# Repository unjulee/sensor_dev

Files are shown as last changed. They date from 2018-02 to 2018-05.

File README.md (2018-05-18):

# sensor_dev
The sensor development team's repo.

## Website
* Please visit our site at [aguaclara.github.io/sensor_dev/](https://aguaclara.github.io/sensor_dev/)

## Team members
* Lois Lee (LL556)
* Srilekha Vangavolu (SV397)
* Hannah Si (HS649)

## Semester Goals
* Our goal is to create a lowcost but efficient concentration detector by essentially hijacking cheap endoscopes/borescopes and merging its function with code and physical additions of our own. By designing a mobile application that utilizes image processing and basic equations relating the image values to concentrations, we can both get a visual of what is going on in each level of depth and determine using a threshold value where the sludge blanket begins.

## Links to Reports and Presentations

[Midterm Symposium Spring 2018](https://docs.google.com/presentation/d/1DQyx87q7LtW5yOaPytrrnAvyGNLM-DLOTYY6XjQVZQw/edit?usp=sharing)
[Final Symposium Spring 2018](https://docs.google.com/presentation/d/1z8MEi4Bpe6GwdDxDbs89RpllG_0ilBI8o5UYnoSLq9U/edit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)

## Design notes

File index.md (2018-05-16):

# Submersible Sensor

Throughout the semester, we will update this page with current tasks, projects completed,
and other things we want to have easy access to.

## About Us

Our goal is to create a lowcost but efficient concentration detector by essentially hijacking 
cheap endoscopes/borescopes and merging its function with code and physical additions of our own.
By designing a mobile application that utilizes image processing and basic equations relating 
the image values to concentrations, we can both get a visual of what is going on in each level of depth
and determine using a threshold value where the sludge blanket begins.

The current members of this subteam are 

* Lois Lee (LL556) 
* Srilekha Vangavolu (SV397)
* Hannah Si (HS649)

## Srilekha's CAD rendering of the MAPE design.
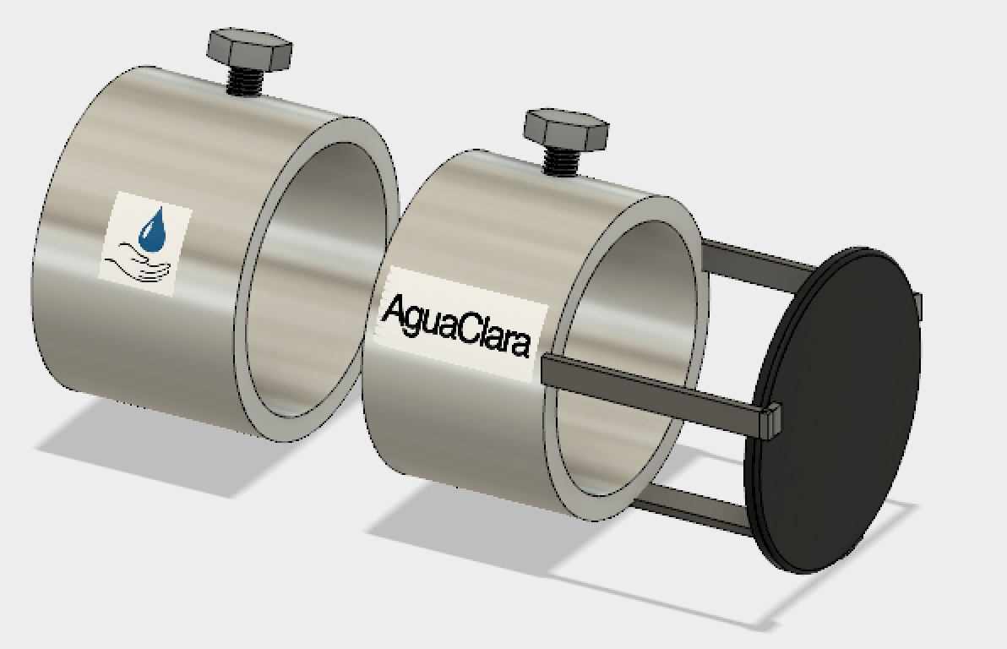
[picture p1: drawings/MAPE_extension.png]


Here is the ruler system we are currently fabricating:

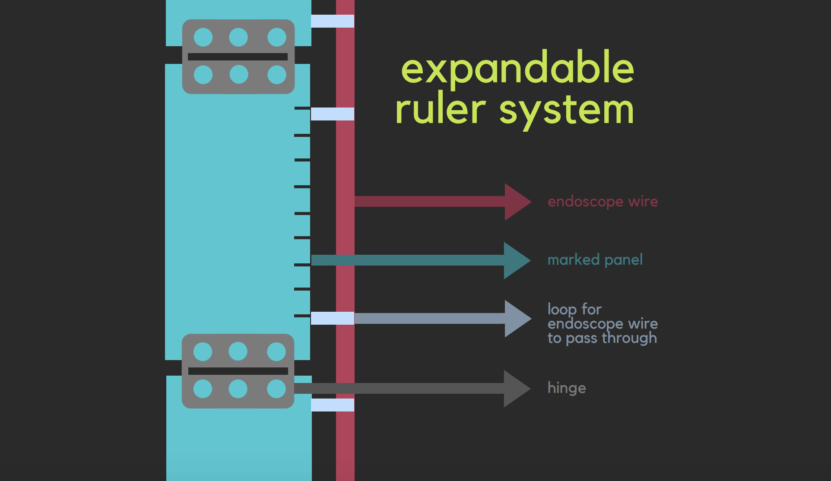
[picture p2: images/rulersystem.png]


To learn more about the specifics of our subteam, please look through the tabs below.

* [Logbook](./logs/logs.md)
* [Manuals](./manuals/manuals.md)
* [Drawings](./drawings/drawings.md)
* [Code](./code/code.md)

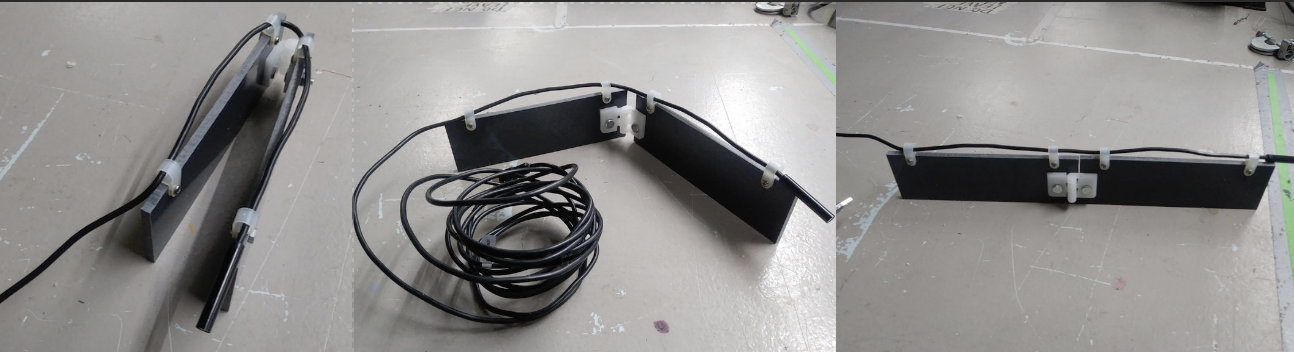
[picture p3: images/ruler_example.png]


## Current Tasks

  - Currently working on fabrication of an expandable ruler system for MAPE design.
  - Currently working on endoscope attachment fabrication and supplies.

Learn more about each of the [components](./components/components.md) of our sensor plan.

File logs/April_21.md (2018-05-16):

It's been a while since we've logged what we've been doing, mostly because we've been looking into supplies.

**Week of April 21st**

Fabrication of the expandable ruler system:
The expandable ruler system replaces our original idea for the reel, just because the reel would not be able to straighten out the
semi-rigid cable for the endoscope. We are using panels connected by hinges with loops on the side to hold the endoscope cable.
The panels will be marked like a ruler so that we can read the height. Some comments on the system:
  - Single hinges didn't work for us, so we may have to use double hinges.
  - In future prototypes, may be thinner.
  
Fabrication of the endoscope attachment:
  - We've found a temporary solution to our matte surface, and also, Hannah's computer case also absorbs almost all light, and we
  realise that color won't be much of a concern for us since it will be greyscaled anyways.
  - We've bought thick wires for the prongs, and also looked for some matte paint, but it is no longer necessary and anyways the most
  matte paint was not good enough.
  - We still need some cylinder shaft collar that will wrap around, and also we need to weld the metal together. 
  
Regarding the light gain problem, we've decided to just black out one half of the endoscope camera and use that as a control since we
can't access the light gain code from the developers of the endoscope. We're still looking for the best way to do that since black tape seems 
not to work as well as we'd like.

51mm for each spacer without screw part

48mm+15 for distance from plate and  endoscope 63

63-51=12 mm

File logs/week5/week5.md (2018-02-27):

# Week 5

We've started preliminary testing using the turbidity sensor after some minor issues regarding connectivity.
We realized that the relation they gave us only works for the voltage range of 2.5-4.2 so we need to set boundaries to make sure we have
a value that makes sense, or output a print statement that accurately shows the lack of information anywhere outside the range.

We've also got our hands on an arduino add on board which could allow us to use bluetooth instead of a cable if we buy an addon.
We got ourselves two pushbuttons from this board but we may need more?

Also we may not need the pushbutton yet, we can just use the reset button and have it determine the offset when we reset manually.

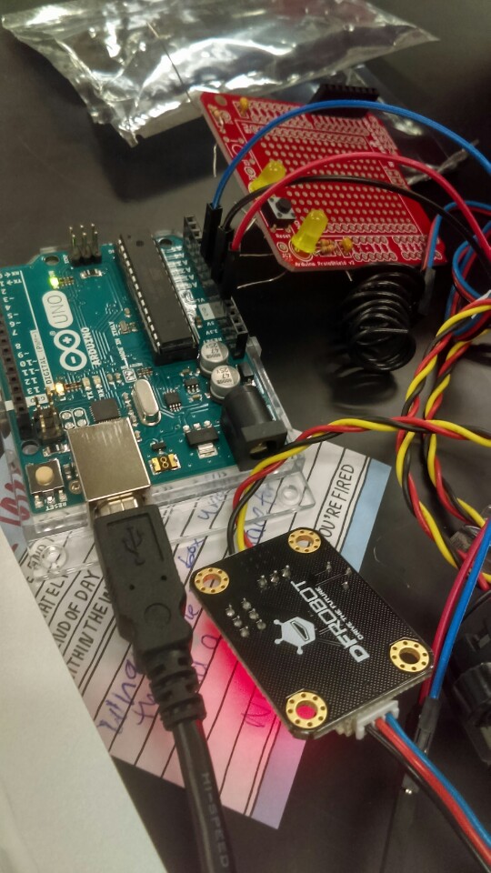
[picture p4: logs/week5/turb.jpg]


THINGS TO DO/ASK:

Is the floc hopper tube smooth?
Also since it's slanted how exactly we are measuring sludge blanket height.
Ask about dark colored sediments

Tasks for next time:
Waterproofing turbidity sensor
Making testing tube (kind of deep)
Once we finish tube start experimenting with borescope.

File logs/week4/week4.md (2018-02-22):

  - Work on testing the turbidity sensor using arduino and code
  - Adjust the relation as necessary
  - Play around with endoscope, maybe start to write pseudocode.
  - Make larger container with matte dark walls and bottom.

  We got access to the maker lab after the training. They have an arduino thankfully so we'll use that for the turbidity sensor.
  We also did some preliminary testing using the endoscope. Mostly trying it out in vials and seeing how it works. The problem is that the 
  LED gives off a reflection so we need a bigger matte wall tank that won't light up.

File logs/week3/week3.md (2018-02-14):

This week we are working on the LED, training and possibly playing around with the turbidity sensors.

* Tuesday
Instead of making the LED, we are looking into buying a small flashlight that is waterproof/water resistant.
Also with the size of the flocc hopper, we need to rethink our entire plan.

```arduino
/*
 * THIS CODE IS FOR AGUACLARA SENSOR_DEV
 * This code's function is to take the input voltage from the turbidity sensor
 * and translate it into a numerical value representing turbidity
 */

int ledPin = 13;

void setup() {
  Serial.begin(9600); //Baud rate: 9600 (this is used for serialPrint)
  pinMode(ledPin, OUTPUT);  //This is to set up the LED
}

void loop() {
  int sensorValue = analogRead(A0);// read the input on analog pin 0:
  float voltage = sensorValue * (5.0 / 1024.0); // Convert the analog reading (which goes from 0 - 1023) to a voltage (0 - 5V):
  Serial.println("this is the voltage reading:");
  Serial.print(voltage); // print out the value you read:
  delay(500);
  Serial.println("converted turbidity:");

  //threshold value to compare to light up LED
}
```

**Displays**
  * We are talking about different displays to display the numerical value. 
  Hannah found a great display that's very affordable.

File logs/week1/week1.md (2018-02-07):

# Week 1
Aguaclara notebook:

* **Get endoscope/borescope (sometimes called snake camera)**
    - buy cheap but okay quality
    - doesn’t have to be good quality because we only need rough idea 
    - But okay because may be used for other things
    - Must be long enough (at least 2m ≈ 6.5ft)
* **Make the cage:**
    - Face camera laterally rather than vertically
    - The cage should also fit an LED screen on opposite side
    - Do you mean: Have LED (single bulb or ring) on opposite side
    - LED should be very bright and close enough so outside light doesn’t interfere
    - Use CAD and 3D printing
    - May need to end a weight on the end so that it’ll sink properly (if device is lowered by a semi-rigid cable, e.g. the endoscope cord)
    - Maybe make it two parts so it clips into place over 
the endoscope and LED
    - To make cage more flexible to multiple lengths/sizes of endoscopes, fix the supporting (hanging) cable relative to the front end of the endoscope 
    - Best if LED is protected with waterproof cage that also holds a removable battery (waterproof phone case?)

* **HEIGHT:**
    - We can have a reel system with notches for a specific length of cord and in that way determine the height of the sludge blanket.

* **LED:**
    - Rubber outing
    - LED connected to battery with a switch/button
    - Keyboard idea: have rubber cover with button over actual button
    - battery

* **Program app:**
    - Connecting the cameras.
    - Confluence camera tab
    - Image Processing
    - OpenCV
    - First connect the endoscope camera to the app
    - Take multiple photos at each level
    - Translate images to grayscale and find average darkness per pixel
    - Average the 3 values and make a relation between the grayscale values and concentration.

* **UI**
    - Kivy
    - Image from endoscope 
    - Need to connect app to usb connected endoscope
    - Take photo button
    - Convert button
    - Using the relation, obviously we need to develop one first through testing and etc.
    - Show the concentration
    - Maybe we could make a conversion button to convert from g/mL and other types of units.

Some notes:
go to the app dev ppl for tips?
ask POST/AIDE what program they use for apps
we should make it an app so it can be used without wifi
The cage maybe can be triangular?
Still have the problem of height?
Upside down ruler system?
SONAR for automatically measuring depth?
Alternative: making ruler markings on the pole that supports the sensors and prompting user to lower it to a specific depth
Secondary consideration: reeling system

Other notes:

Sludge blanket threshold coded in? So after conc conversion, if reaches threshold, tells you you are in the sludge blanket? Maybe then trigger sonar and find distance?

Ask concentration at sludge blanket

How to waterproof circuits?
LED plate...maybe not rechargeable?

https://www.amazon.com/AGPtek-Submersible-Brightness-Battery-Decoration/dp/B00T9GGWGC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 
Something like this but problem with this is that it dims plus cannot turn on and off easily

Even better buy screwable waterproof disc shaped cases, make own led
Waterproof phone case

* [Waterproof case](https://www.amazon.com/Universal-Waterproof-Case-JOTO-CellPhone/dp/B00LBK7QBY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 )
* [LED from Sparkfun](https://www.sparkfun.com/products/13902 )
* [LED from Sparkfun](https://www.sparkfun.com/products/11118)
* [LED from Sparkfun](https://www.sparkfun.com/products/11148)
* [LED from Sparkfun](https://www.sparkfun.com/products/13105)

Endoscope/Borescopes
* [Depstech Endoscope](https://www.amazon.com/Depstech-Semi-rigid-Inspection-Waterproof-Adjustable/dp/B0749BQG1B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)
    - **Pros**: micro USB, USB, USB-C
    - **Cons**: can only dimmed? (possibly solved by covering up?)
    - Resolution: 2.0 MP (1280 x 960)
    - 0.33inch/8.5mm diameter
    - Semi-rigid (bendable, can hold its shape)
* [Endoscope other](https://www.amazon.com/Endoscope-Borescope-Waterproof-Inspection-Adjustable/dp/B01N19YCC3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) 
    - 50 ft, not rigid
    - **Pros:** 
    - **Cons:** “Due to the long cable length, the using experience with android phone is not very good, it will have image delay.”
    - Resolution:1280x720
    - 0.33inch(8.5mm)

PLAN:

Decide on a product
Ask monroe about the Amazon buy
Talk about app with ppl
Work on design for LED
Once the product comes, make a cage

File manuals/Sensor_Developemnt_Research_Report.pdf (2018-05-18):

# Sensor Development, Spring 2018

### Lois Lee, Srilekha Vangavolu, Hannah Si

### May 18, 2018

# Abstract

The goal of the Sensor Development subteam is to create sensors that monitor water quality during the water treatment process. The subteam has previously developed particle concentration and turbidity sensors, including a fluidized bed solids detector for in-lab experiments conducted in piping. This semester, the subteam is designing a submersible solids detector for measuring turbidity and sludge blanket height in sedimentation tanks. The aim is to create a turbidimeter and sludge blanket height detector that is more affordable, easier to fabricate, and more usable than those currently used in the field. Two designs involving an endoscope and photodiode, respectively, are being compared for accuracy and usability.

# Introduction

The Sensor Development subteam creates sensors to monitor water quality in various stages of the AguaClara wastewater and drinking water treatment processes, for purposes not limited to facilitating research, gauging the efficacy of the treatment process, and detecting problems in the treatment process. The subteam's first project was to develop a gas measurement sensor that would improve experimentation in the Anaerobic Fluidized Bed (AFB) Reactor and Upflow Anaerobic Sludge Blanket (UASB) wastewater subteams (Fall 2016 report). (https://www.overleaf.com/read/jyzxckcyzrfz#/20452187/) Afterward, the subteam worked on a fluidized bed solids concentration sensor to measure clay particle concentration in the high rate sedimentation (HRS) process for drinking water treatment. Last semester's team refined the fluidized bed solids concentration sensor, finishing with a working and reliable sensor (Fall 2017 report). (https://www.overleaf.com/10952600qfscwzjvygcj#/41225444/) This semester, the subteam is building a submersible solids concentration sensor to measure turbidity and the height of the sludge blanket in the sedimentation tanks of drinking water treatment plants.

This semester, the Sensor Development subteam is implementing two new designs for a submersible solids concentration, or turbidity sensor based on the two ideas recommended by our advisor and by other AguaClara members. The primary design features an endoscope and visual processing in a mobile application, providing an intuitive and appealing user interface. In the second design, a pre-developed analog turbidity sensor is interfaced with a microcontroller, a system that is easier and cheaper to implement but provides a difficult user interface. The end goal of both designs is to provide the treatment plant operators and members of other subteams with a more affordable, easily used and maintained, and instantaneous method of not only determining the height of the sludge blanket, but also measuring the turbidity of the sedimentation tank fluid at varying depths.

# Manual

# Product Details

Mobile Application-Processed Endoscope (MAPE) Turbidity Sensor

The mobile application-processed endoscope turbidity sensor encompasses three main physical components: 1) the endoscope, 2) an expandable ruler system, and 3) a mobile device, such as a smartphone, provided by the user. The sensor system also contains one software component: a mobile application (on the mobile device), that processes and displays data from the endoscope and interacts with the user.

1. Endoscope

An endoscope is a type of borescope, an optical instrument that is typically slender, illuminated by built in lights, and attached to a long cable, making it suitable for viewing inside otherwise inaccessible places. An endoscope specifically was chosen for this turbidity sensor for its small size, accuracy, water resistance, and device compatibility.

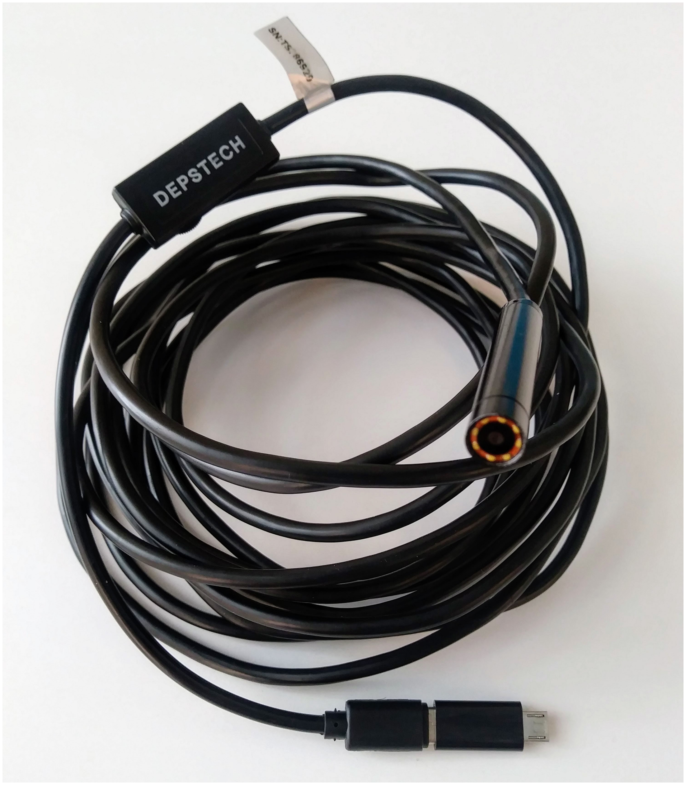
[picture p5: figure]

Figure 1. This endoscope purchased from Depstech® features a 5 meter-long semirigid cable, a 2.0 MP camera ringed with adjustable LED lights, and a type-c USB end with complementary USB and micro-USB extensions. See Special Components for more details.
The role of the endoscope is to capture images of the sedimentation tank fluid at certain depths. The images will be lit by its light source, a ring of LED lights around the camera lens. To restrict its view to such depths, the endoscope is accompanied by a non-reflective material, such as matte rubber, fixed no more than an inch in front of its lens. The turbidity of the fluid is thus measured by intensity of light reflected back to the endoscope due to the presence of suspended solids. In fluid of low solids concentration, the endoscope should detect minimal reflection of light.
2. Expandable Ruler System
Instead of using a marked reel, we are fabricating an expandable ruler system to measuring the length the endoscope has been lowered by. This system consists of multiple 20 cm long PVC panels marked at each centimeter. The panels are connected by hinges to expand and collapse in an accordion style, while the endoscope cable runs down the side of the panels through a series of loops, folding with the panels (see Figure 2). The width of the panels must be around 2 inches or less in order to fit through the sedimentation tank opening.
Thus, the user may lower the system panel by panel until the endoscope has reached the sludge blanket. The height of the sludge blanket would equal the depth of the endoscope (measured by the panel markings) subtracted from the total height of the sedimentation tank. The advantages of this expandable system are its collapsibility, making it ideal for transport, and the rigid backing it provides so that the endoscope wire, which is semi-rigid, remains perpendicular to the bottom of the tank, ensuring an accurate height reading.

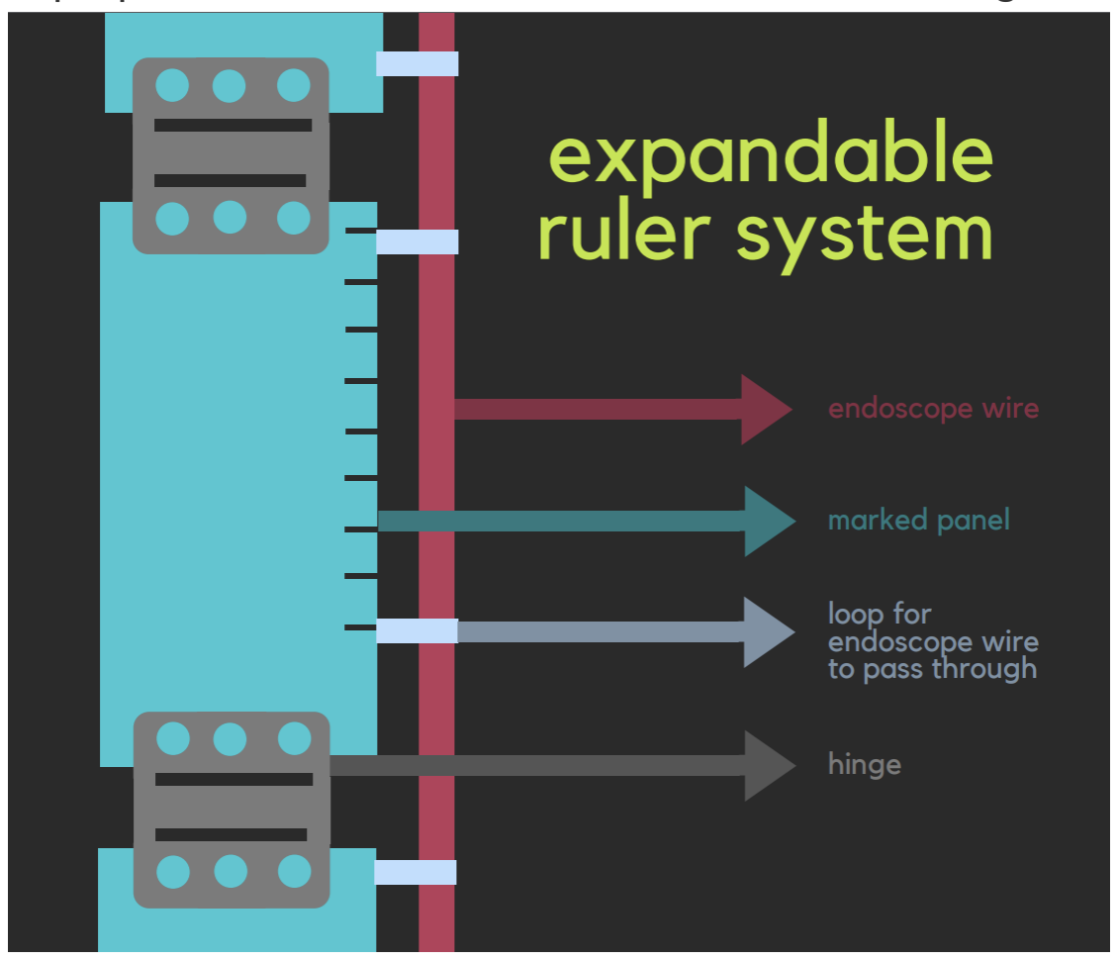
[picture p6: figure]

Figure 2. The expandable ruler system consists of multiple marked panels connected by hinges end-to-end. (Only a portion of the entire system is shown.) The endoscope cable runs down the side of the panels through a series of loops.

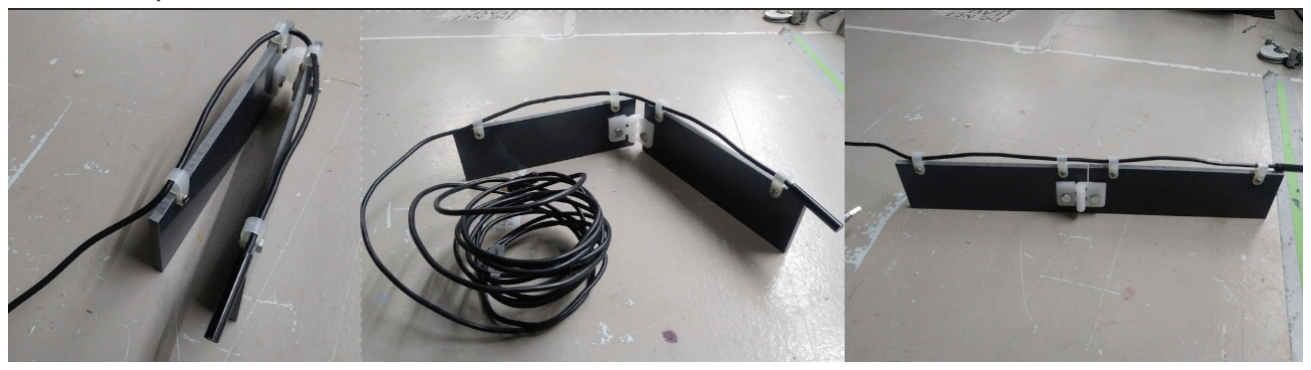
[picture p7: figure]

Figure 3. Above is a prototype of the expandable ruler system, constructed with two PVC panels, plastic loops, and plastic hinges. The prototype is able to collapse (left) for compact storage and also expand (right) to provide a straight, rigid backing for the endoscope cord when hung vertically.
3. Mobile Device and Application

The mobile device is a smartphone or tablet computer provided by the user. It connects to the endoscope by a USB-C, USB, or Micro USB connection and runs the mobile application that we are in the process of programming.
The application will collect live images taken by the endoscope, process each one for average light intensity, and calculate the turbidity of the fluid in each image. This calculation will use an empirically obtained correlation between turbidity and the intensity of reflected light (yet to be developed), as well as offset for any light detected during calibration in clear fluid. See MAPE Code for sample processing code.
The mobile application will also provide a user-friendly interface by directing the user to calibrate the sensor, prompting the user to lower the endoscope to greater depths, and displaying the camera stream and calculated turbidity at each depth. In addition, it will record and graphically plot each calculation to track the change in turbidity as the endoscope nears the sludge blanket. The height of the sludge blanket can be determined once the turbidity rapidly increases or reaches a threshold value.

Microcontroller-Interfaced Analog (MIA) Sensor

The microcontroller-interfaced analog sensor also encompasses three main physical components: 1) the analog photodiode, 2) an expandable ruler system, and 3) a microcontroller programmed to convert and displays data from the endoscope and interact with the user.

1. Analog Photodiode

We had previously been using an analog turbidity sensor, however because of its unreliability and sensitivity to noise, we were forced to use a photodiode instead. The specific photosensor that we used was the TEMT6000 Ambient Light Sensor. See Special Components for details and image source.
2. Expandable Ruler System

This expandable ruler system is the same as that of the MAPES sensor system. We will fabricate it in the same way but the endoscope will be replaced by the photosensor.
3. Microcontroller

The microcontroller we are using is the Arduino® UNO. The Arduino will read the output from the analog photosensor and convert that value into a turbidity reading. The developers of the sensor have published a tentative relation; however, further testing must be done to prove the validity of the relation. If the readings do not correlate to accurate turbidity, we may have to empirically develop a relation of our own. The microcontroller will also feature a digital display for the turbidity reading and a pushbutton for calibrating the sensor in clear fluid.
See Special Components for details on the Arduino microcontroller and MIA Code for sample code.

# Fabrication

Fabrication for the MAPE Turbidity Sensor

The only modification necessary for the endoscope is the addition of an extension for the non-reflective material. The extension includes two rectangular plates, one attached to the endoscope body, and the other extending off the endoscope and holding the non-reflective material in front of the camera lens. The two plates are screwed to and connected by two standoffs. The former standoff contains a hole the size of the endoscope so that the endoscope may slide through and be fixed to the plate with glue or another sealant.

The optimal distance from the camera lens to the non-reflective material is determined as the lowest distance for which the material reflects an acceptably low amount of light (with "acceptable" defined as reflecting light almost uniformly rather than in a bright spot or halo). Note that minimizing the distance minimizes the size and diameter of the sensor. For our endoscope and with matte rubber as the non-reflective material, we estimate a distance of 1.5 cm. Using the distance ( ) and the field of view ( ) angle of the endoscope (60º for ours), the minimum width ( ) of the non-reflective material and the plates is:

All parts can be made of plastic or metal, except the non-reflective material, for which we suggest matte rubber. Below is a rendering of the extension.

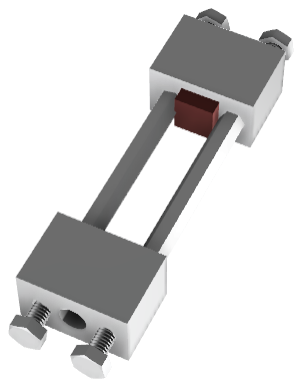
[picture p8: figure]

Figure 5. The extension includes two rectangular plates, one attached to the endoscope body, and the other extending off the endoscope and holding the non-reflective material in front of the camera lens. The two plates are screwed to and connected by two standoffs. Find the Fusion 360™ file for the extension here. (https://github.com/AguaClara/sensor_dev/blob/master/drawings/Endo%20v9.iges)
Variables

Table 1: List of Variables Used in MAPE Sensor Fusion Drawing

Variables | Description | Value
rec_width | width of plate | 2 cm
rec_length | length of plate | 3.5 cm
standoff_diam | diameter of standoffs | .7 cm
rec_thickness | thickness of metal plates | 3 cm
endoscope_diam | diameter of endoscope | 5/16 in
screw_diam | diameter of threads | 5/32 in
disttoedge | distance from screw to edge of plate | .05 cm

D θ
W

W = D ⋅ 2tan(
2

### θ ) = 1.5 ⋅ ≈ 1.732cm 3

2

Variables | Description | Value
screw_leng | length of threads | .6 cm
screw_poly | diameter of hex screw head rubber | .7 cm
chamfer | length of chamfer at bottom of screw | .6 cm
fillet | length of fillet beneath head of screw | .6 cm

Fabrication for the MIA Turbidity Sensor

The main fabrication required for the MIA turbidity sensor is waterproofing the circuitry. The wires are hidden in flexible tubing which is thick enough to make sure that no water will enter and damage the sensor. We are still experimenting with ways to waterproof the photosensor however, because we do not want to damage the circuitry. The LED should be easily waterproofed with some silicon, which we plan to do the following semester.

We plan to fabricate a case for the microcontroller for protection and easy handling and for holding the digital display. It will also include a rubber button connected to a pushbutton on the microcontroller to allow the user to calibrate the sensor. The design for the case not yet been finalized.

Fabrication for the Expandable Ruler System
As mentioned before, the Expandable Ruler System is made up of multiple 20 cm long PVC panels marked at each centimeter. Each of the panels are connected by double hinges to expand and collapse. The endoscope cable runs down the side of the panels through a series of loops which we attach to the side of the PVC panel (see Figure 2). Although we used single hinges for the prototype (see Special Components), we plan to use a double hinge in future iterations. Please refer to Figure 3 for the prototype.

# Special Components

### MAPES Turbidity Sensor

Endoscope/ Borescope:
The endoscope we used was purchased through Amazon and was developed by Depstech®. Click here to view. (https://www.amazon.com/Depstech-Semi-rigid-Inspection-Waterproof-Adjustable/dp/B0749BQG1B) Product specifications can be found on the given website as well. Although we chose this particular endoscope, there are other similarly viable endoscopes and borescopes available.

### MIA Turbidity Sensor

Analog Turbidity sensor
The specific photosensor used was the TEMT6000 Ambient Light Sensor made by SparkFun. TEMT6000 is a silicon NPN epitaxial planar photo-transistor in a miniature transparent mold for surface mounting onto a printed circuit board. The device is sensitive to wavelengths from 390 nm to 700 nm. It is available here. (https://www.sparkfun.com/products/8688)

Arduino® UNO
The Arduino UNO can be purchased through the Arduino website. (https://www.arduino.cc/) The Arduino IDE is also available here (https://www.arduino.cc/en/Main/Software) for free.

### Expandable Ruler System

Hinges
The plastic hinges used in the prototype can be found here. (https://www.mcmaster.com/#1635a25/=1c2z1rq)

# Experimental Methods

## Current Experimental Methods

Because we are still in the fabrication and programming process, we are not able to test at this time. However, we are intermittently checking to see if the analog photosensor for the MIA turbidity work correctly. We do this by using print statements and checking to see that there is ample fluctuation and a significant difference between high and low turbidities.

int ledPin = 13; | //declaration for LED
int button = 11; | //digital input of the pushbutton
int offset = 0; | //set the offset as zero for now
int turb_input = A1; | //input in A0 from sensor
int flag = 0; | //if flag is 1, start loop

void setup() {
// put your setup code here, to run once: Serial.begin(9600);
}

void loop() {
// put your main code here, to run repeatedly: int test=analogRead(turb_input); Serial.println('\n');
Serial.println("reading from the input"); Serial.println(test);

}

## Future Experimental Methods

To test our sensors, we will submerge each into fluids of known solids concentration and turbidity. We will then analyze collected outputs for a relation between actual concentration and measured turbidity. It may also be necessary to test the effects of different types, particularly different colors, of sediment on the turbidity readings. However, we are not yet at the testing phase and have no experimentation details yet to report.

# MAPE Turbidity Sensor Code

This is a sample of code written in Java for displaying a video stream from the endoscope and processing its images for average light intensity. For the full set of classes required for this program, browse our Github repository at AguaClara/sensor_dev/code/Endoscope Pilot Code (or click here. (https://github.com/AguaClara/sensor_dev/tree/master/code/Endoscope%20Pilot%20Code)

/* Framework for video frame capture, conversion, and display adapted from * http://computervisionandjava.blogspot.com/2013/10/java-opencv-webcam.html*/

import java.awt.Graphics;
import java.util.Date;

import javax.swing.JFrame;
import javax.swing.JPanel;
import javax.swing.border.EmptyBorder;

import org.opencv.core.Mat;
import org.opencv.imgproc.Imgproc;

public class EndoscopeFrame extends JFrame { private JPanel contentPane;
VideoCap videoCap;

public static void main(String[] args) {
try {
EndoscopeFrame frame = new EndoscopeFrame(); frame.setVisible(true);
} catch (Exception e) {
e.printStackTrace();
}
}

public EndoscopeFrame() {
setDefaultCloseOperation(JFrame.EXIT_ON_CLOSE); setBounds(0, 0, 1280, 960);
contentPane = new JPanel(); contentPane.setBorder(new EmptyBorder(5, 5, 5, 5)); setContentPane(contentPane);
contentPane.setLayout(null);

videoCap = new VideoCap(1);
//0 or nothing for default camera (for a computer, the webcam)
//1 or higher for additional cameras (e.g. the USB endoscope camera)

new MyThread().start();
}

public void paint(Graphics g){
g = contentPane.getGraphics();
g.drawImage(videoCap.getOneImgFrame(), 0, 0, this);

if (counter % 10 == 0)
System.out.println("Average Light: " + averageLight(videoCap.mat2Img.mat, 10)); }

public static int averageLight(Mat mat, int spacing) {
Imgproc.cvtColor(mat, mat, Imgproc.COLOR_BGR2GRAY);
int[][] pixelShades = new int[mat.rows()/spacing+1][mat.cols()/spacing+1]; int sum = 0;

for (int r = 0; r < mat.rows(); r += spacing) { for (int c = 0; c < mat.cols(); c += spacing) { pixelShades[r/spacing][c/spacing] = (int) mat.get(r, c)[0];

sum += pixelShades[r/spacing][c/spacing];
}
}

return sum/pixelShades.length/pixelShades[0].length; }

class MyThread extends Thread{ @Override
public void run() {
while (true) {
repaint();
try { Thread.sleep(30);
} catch (InterruptedException e) { } }
}
}
}

Sample Output:

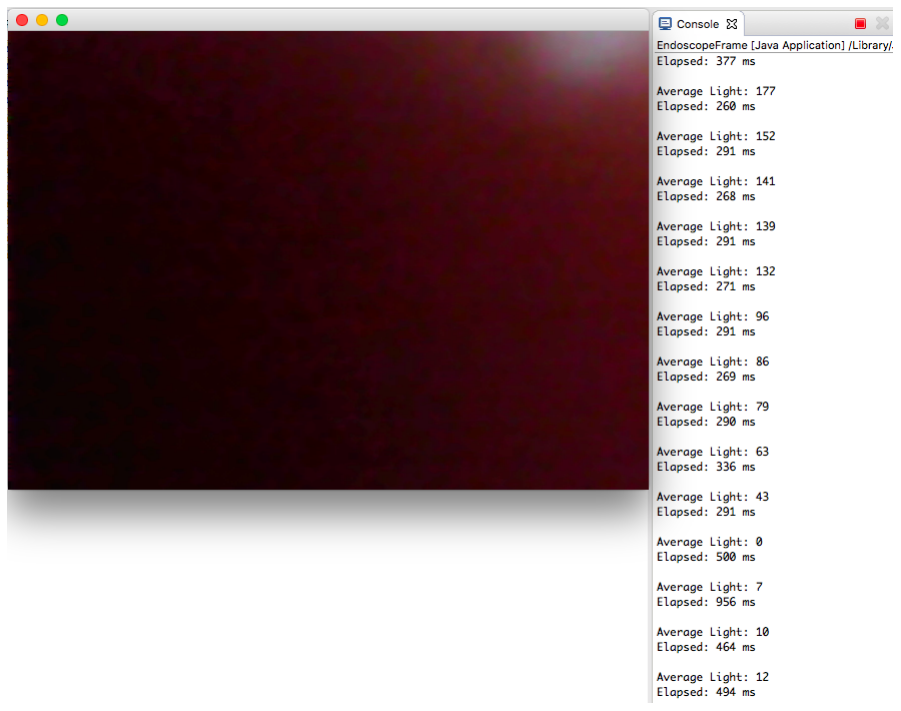
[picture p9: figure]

Figure 7. Above is a sample output of the program for the MAPE turbidity sensor produced by exposing the camera to light and then quickly covering it. Hence, the "Average Light" values that fall from near 200 to 0. Additional code was written for printing elapsed time between calculations.

Below is a Java file for a mobile Android application that streams camera feedback from the phone's own camera(s) with constant exposure. For future work, the application must access the endoscope, an external camera to the smartphone, and integrate the image processing code from above. For the full project, written in

Android Studio® using Android libraries, browse our Github repository at AguaClara/sensor_dev/code/AguaClara Turbidity (or click here). (https://github.com/AguaClara/sensor_dev/tree/master/code/AguaClara%20Turbidity)

package me.aguaclaraturbidity;

import android.content.pm.PackageManager; import android.support.v4.app.ActivityCompat; import android.support.v4.content.ContextCompat; import android.support.v7.app.AppCompatActivity; import android.os.Bundle;

import android.util.Log;
import android.view.SurfaceHolder;
import android.view.SurfaceView; import android.hardware.Camera; import android.widget.SeekBar; import android.widget.TextView;

import java.io.IOException;

public class MainActivity extends AppCompatActivity implements SurfaceHolder.Callback, Camera.Pre private Camera camera;
private Camera.Parameters camParams;

@Override
public void onCreate(Bundle savedInstanceState) { super.onCreate(savedInstanceState);

setContentView(R.layout.activity_main);
SurfaceView cameraPreview = (SurfaceView) findViewById(R.id.camera_preview);

ActivityCompat.requestPermissions(this, new String[]{android.Manifest.permission.CAMERA},

if (ContextCompat.checkSelfPermission(getApplicationContext(), android.Manifest.permissio == PackageManager.PERMISSION_GRANTED) {
openCamera(0);
try {
cameraPreview.getHolder().addCallback(this); camera.setPreviewDisplay(cameraPreview.getHolder()); camera.setPreviewCallback(this); camera.startPreview();
} catch (IOException e) {
e.printStackTrace();
}
}
}

public void openCamera(int id){ releaseCameraAndPreview();
camera = Camera.open(id);
camera.setDisplayOrientation(90); camParams = camera.getParameters(); }

private void releaseCameraAndPreview() { if (camera != null) {
camera.stopPreview();
camera.release();

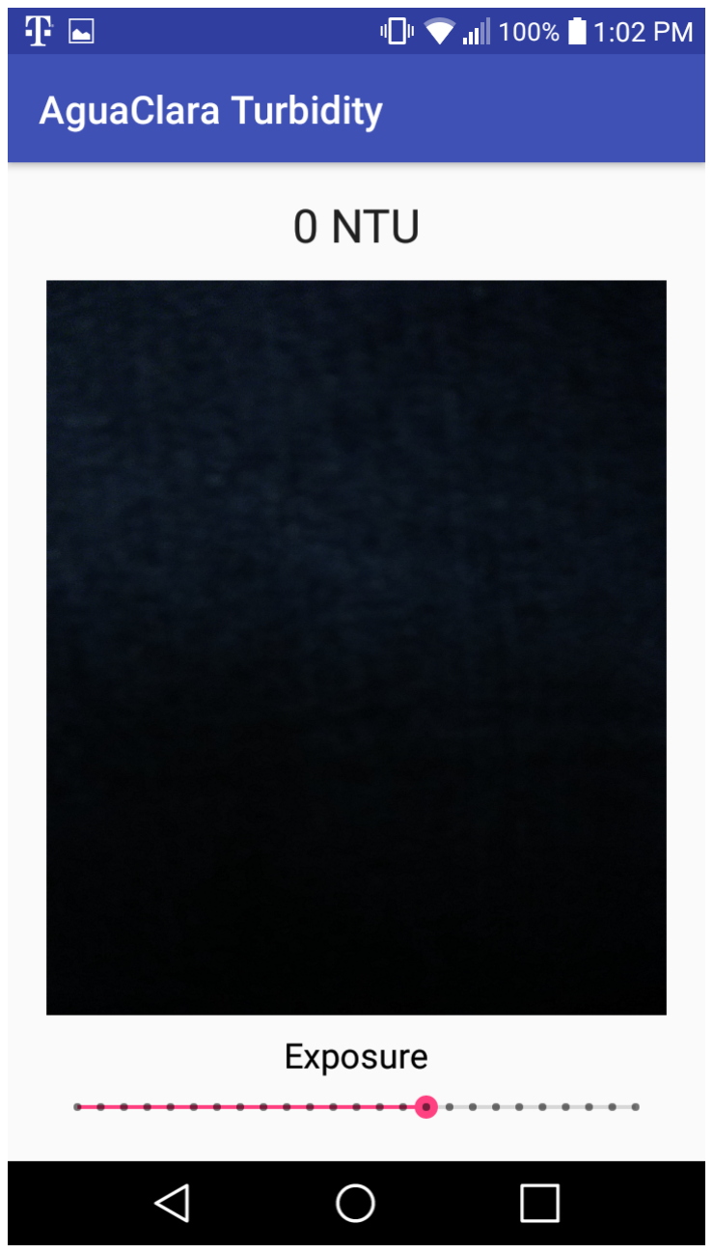
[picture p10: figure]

Figure 8. This is a screenshot of the mobile Android application for the MAPE turbidity sensor. The camera feedback is from the phone's rear camera, as the application is not yet able to access an external camera such

camera = null;
}
}

@Override
public void surfaceCreated(SurfaceHolder surfaceHolder) { try {
camera.setPreviewDisplay(surfaceHolder);
camera.startPreview();
} catch (IOException e) {
Log.d("View", "Error setting camera preview: " + e.getMessage()); }
}

@Override
public void surfaceChanged(SurfaceHolder surfaceHolder, int i, int i1, int i2) { }

@Override
public void surfaceDestroyed(SurfaceHolder surfaceHolder) {
if (camera != null) {
camera.stopPreview();
}
}

@Override
public void onPreviewFrame(byte[] bytes, Camera camera) { camParams.setExposureCompensation(0); camera.setParameters(camParams);
}
}

as the endoscope. The user may adjust the exposure level, though between adjustments the exposure is held constant.

# MIA Code

This C code is to program the Arduino Uno for the MIA sensor. It uses the input from the sensor and the relation provided by the vendors and developers to determine a turbidity. (Programmed with the Arduino IDE)

//global variables

int ledPin = 13; | //declaration for LED
int button = 11; | //digital input of the pushbutton
int offset = 0; | //set the offset as zero for now
int turb_input = A0; | //input in A0 from sensor
int flag = 0; | //if flag is 1, start loop
float turbidity = 0.0; | //turbidity
int threshold = 700; | //threshold turbidity for sludge blanket

void setup() {

Serial.begin(9600); | //Baud rate: 9600
pinMode(ledPin, OUTPUT); | //This is to set up the LED
pinMode(turb_input, INPUT); | //This is to set up the input from sensor
pinMode(button, INPUT); | //This is to set up the input from pushbutton

//CALIBRATION
Serial.println('\n');
Serial.println("Please calibrate the sensor by pressing the button");

//PUSHBUTTON
if (digitalRead(button)==LOW){
flag = 0;
}

else if(digitalRead(button) == HIGH){ offset = analogRead(turb_input); Serial.println('\n');
Serial.print("this is the offset value:"); Serial.println(offset);
delay(500);
flag = 1;
}
}

void loop() {

// if (flag == 1){
int sensorValue = analogRead(turb_input);// read the input on A0:

// Convert the analog reading (which goes from 0 - 1023) to a voltage (0 - 5V): float voltage = sensorValue * (5.0 / 1024.0); Serial.println("____________________________________");
Serial.print("this is the reading from the analog:"); Serial.println(sensorValue); // print out the value you read:

Serial.print("this is the voltage reading:"); Serial.println(voltage); // print out the value you read:

// Convert voltage to turbidity
// relation from page is -1120.4x^2 +5742.3x-4352.9
// only supports voltages of 2.5-4.2 for the relation if (voltage > 2.5 && voltage < 4.2){
turbidity = (voltage*voltage*(-1120.4))+(voltage*5742.3)-4352.9-(offset); }
else if (voltage < 2.5){
turbidity = 3000;
}
else if (voltage > 4.2){
turbidity = 0;
}
Serial.print("this is the turbidity reading:"); Serial.println(turbidity); // print out the value you read: delay(500);

//threshold value to compare to light up LED
if (turbidity > threshold){
digitalWrite(ledPin, HIGH);
Serial.println("YOU ARE NOW IN THE SLUDGE BLANKET"); }
else {
digitalWrite(ledPin, LOW);
}
}

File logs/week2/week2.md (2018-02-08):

* **Tuesday**
  - We've decided on getting the Depstech one.  
  - Grading meeting today with Natalie
  - Hannah will meet with the coding POST people on Wednesday
  - Meeting with RA on Saturday.
* **Wednesday**
  - Emailed Casey about Amazon order.
  - Hannah's meeting.
* **Thursday**
  - Tutorials and training.
  - Work on the python one next week.

  While we wait for the endoscope order to go through, 
  we can start designing an LED and start planning the app.

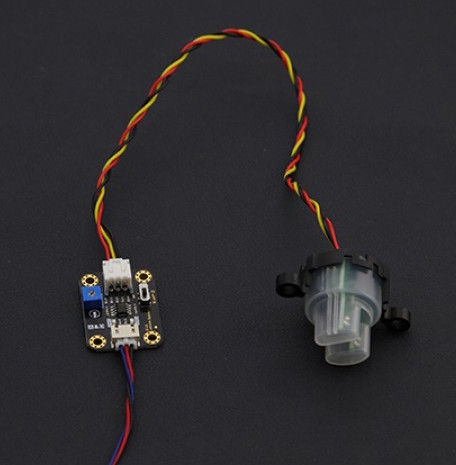
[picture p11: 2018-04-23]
images/analog_turbidity_sensor.jpg

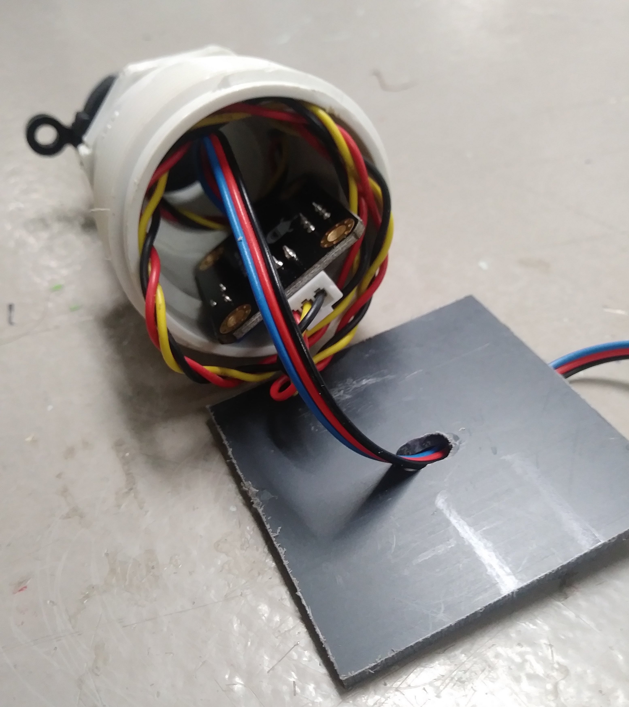
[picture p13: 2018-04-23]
images/MIA_inside.png

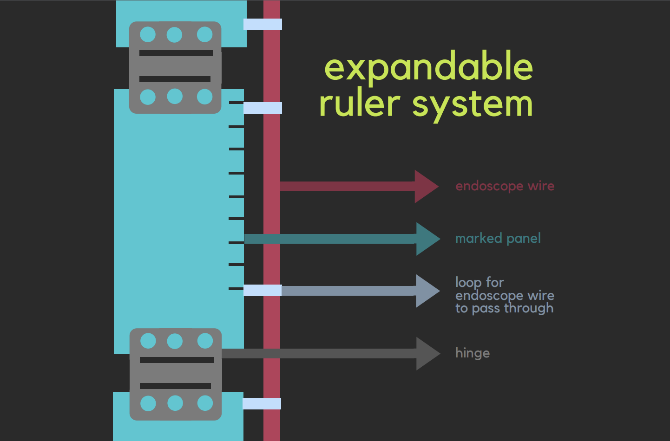
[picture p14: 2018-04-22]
images/rulersystem_2.png

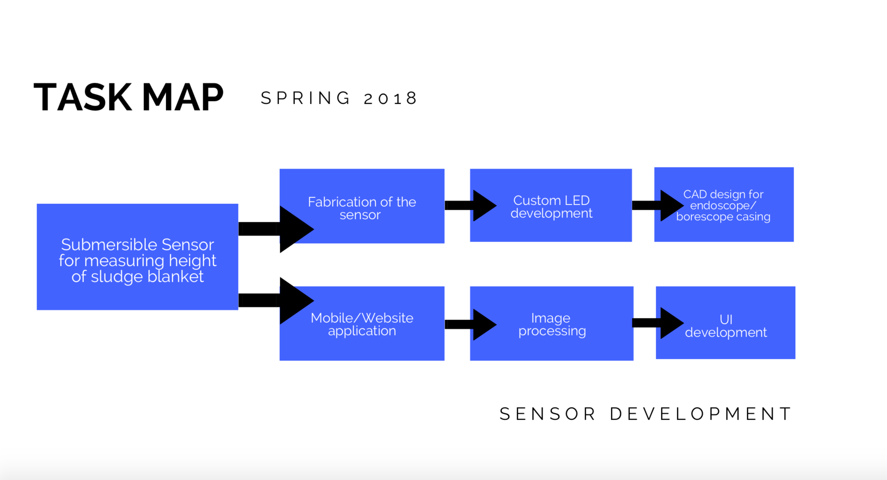
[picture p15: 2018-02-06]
taskmap.jpg

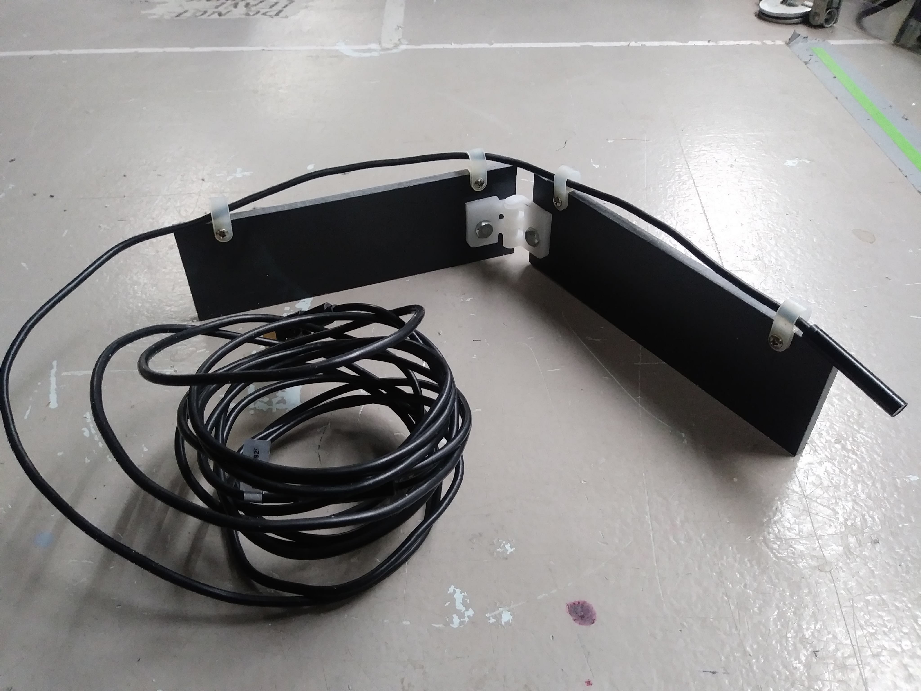
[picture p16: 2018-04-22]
images/ruler2.jpg

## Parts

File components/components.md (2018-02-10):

# Components of the Sensor

We will update each page about each component as time goes on:
* [LED](LED.md)
* [Casing](casing.md)
* [application](app.md)

# The basics:

The primary function of this submersible sensor is to give us real time footage of the particles suspended
within the water and simultaneously provide us with accurate concentration readings so we can have a viewable
and numerical understanding of what happens within the tanks. That being said the mobile application
will utilize image processing to read concentration.

Besides the programming component with the mobile/web application, 
we also want to change some physical aspects regarding the endoscope/borescope.
This will have 2 parts to it. 

The first is a 3D printed casing to bend the endoscope camera 90 degrees. 
The endoscope originally comes straight, so if we lower it down, 
it will have a vertical view downwards of the tank. This will most likely disrupt the particles and 
cause an inaccurate reading of the concentration. Thus we want to shift the camera
so it faces horizontally. We will achieve this through use of a 3D printed casing that will fit around the
scope and hole a bent shape. This casing will also house the LED opposite the scope.

The second component is an LED. The endoscope comes with LEDs of its own however, because this light will
reflect off the particles and change our readings, we need to dim the LEDs on the endoscope down and make an
LED facing the endoscope, so that the silhouette of the particles shows and it'll be easier to read the image.

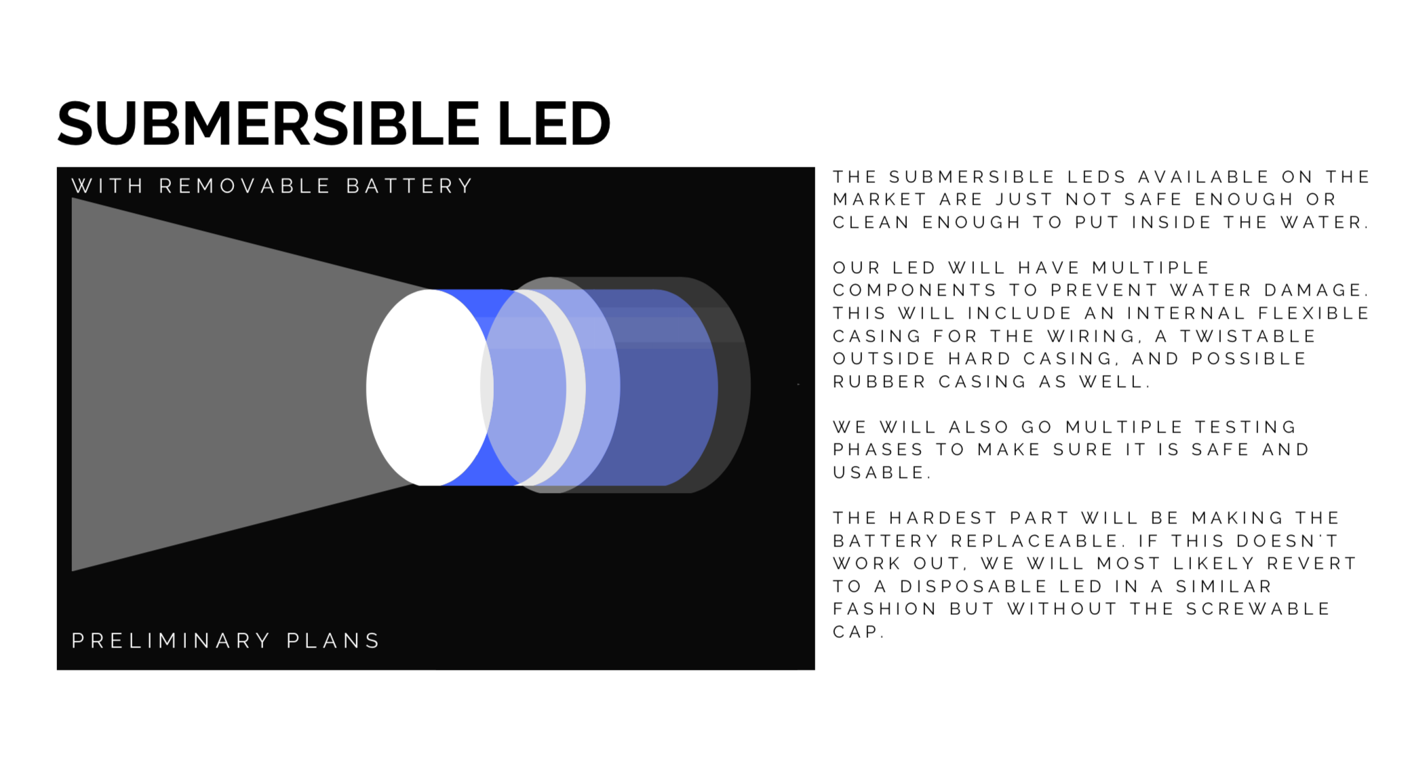
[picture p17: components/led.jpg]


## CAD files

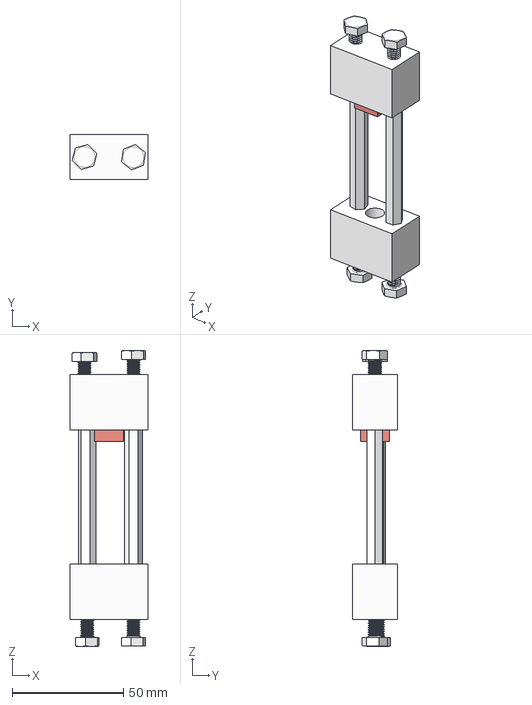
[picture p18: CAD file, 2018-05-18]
drawings/Endo v9.iges
35.0 x 20.0 x 133.0 mm

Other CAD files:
drawings/Hinges/DoubleHinge v7.f3d
drawings/MAPE v5.f3d
drawings/MAPE v8.f3d
drawings/Old MAPE/MAPE v5.f3d
drawings/Old MAPE/MAPE v8.f3d
drawings/Screw_stand v10.f3d

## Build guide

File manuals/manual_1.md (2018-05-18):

# Sensor Development, Spring 2018
#### Lois Lee, Srilekha Vangavolu, Hannah Si
#### May 18, 2018

## Abstract
<!--Summary of previous work, goals and objectives, accomplishments, and future work. -->

The goal of the Sensor Development subteam is to create sensors that monitor water quality during the water treatment process. The subteam has previously developed particle concentration and turbidity sensors, including a fluidized bed solids detector for in-lab experiments conducted in piping. This semester, the subteam is designing a submersible solids detector for measuring turbidity and sludge blanket height in sedimentation tanks. The aim is to create a turbidimeter and sludge blanket height detector that is more affordable, easier to fabricate, and more usable than those currently used in the field. Two designs involving an endoscope and photodiode, respectively, are being compared for accuracy and usability.

## Introduction
<!--Explain how the completion of your challenge will affect AguaClara and the mission of providing safe drinking water (or sustainable wastewater treatment!). If this is a continuing team, how will your contribution build upon previous research? What needs to be further discovered or defined? If this is a new team, what prompted the inclusion of this team?-->

The Sensor Development subteam creates sensors to monitor water quality in various stages of the AguaClara wastewater and drinking water treatment processes, for purposes not limited to facilitating research, gauging the efficacy of the treatment process, and detecting problems in the treatment process. The subteam's first project was to develop a gas measurement sensor that would improve experimentation in the Anaerobic Fluidized Bed (AFB) Reactor and Upflow Anaerobic Sludge Blanket (UASB) wastewater subteams ([Fall 2016 report]( https://www.overleaf.com/read/jyzxckcyzrfz#/20452187/)). Afterward, the subteam worked on a fluidized bed solids concentration sensor to measure clay particle concentration in the high rate sedimentation (HRS) process for drinking water treatment. Last semester's team refined the fluidized bed solids concentration sensor, finishing with a working and reliable sensor ([Fall 2017 report](https://www.overleaf.com/10952600qfscwzjvygcj#/41225444/)). This semester, the subteam is building a submersible solids concentration sensor to measure turbidity and the height of the sludge blanket in the sedimentation tanks of drinking water treatment plants.

This semester, the Sensor Development subteam is implementing two new designs for a submersible solids concentration, or turbidity sensor based on the two ideas recommended by our advisor and by other AguaClara members. The primary design features an endoscope and visual processing in a mobile application, providing an intuitive and appealing user interface. In the second design, a pre-developed analog turbidity sensor is interfaced with a microcontroller, a system that is easier and cheaper to implement but provides a difficult user interface. The end goal of both designs is to provide the treatment plant operators and members of other subteams with a more affordable, easily used and maintained, and instantaneous method of not only determining the height of the sludge blanket, but also measuring the turbidity of the sedimentation tank fluid at varying depths.

# Manual

## Product Details

**Mobile Application-Processed Endoscope (MAPE) Turbidity Sensor** <br/>
The mobile application-processed endoscope turbidity sensor encompasses three main physical components: 1) the endoscope, 2) an expandable ruler system, and 3) a mobile device, such as a smartphone, provided by the user. The sensor system also contains one software component: a mobile application (on the mobile device), that processes and displays data from the endoscope and interacts with the user.

1. Endoscope <br/>
   An endoscope is a type of borescope, an optical instrument that is typically slender, illuminated by built in lights, and attached to a long cable, making it suitable for viewing inside otherwise inaccessible places. An endoscope specifically was chosen for this turbidity sensor for its small size, accuracy, water resistance, and device compatibility. <br/>

   <p align="center">
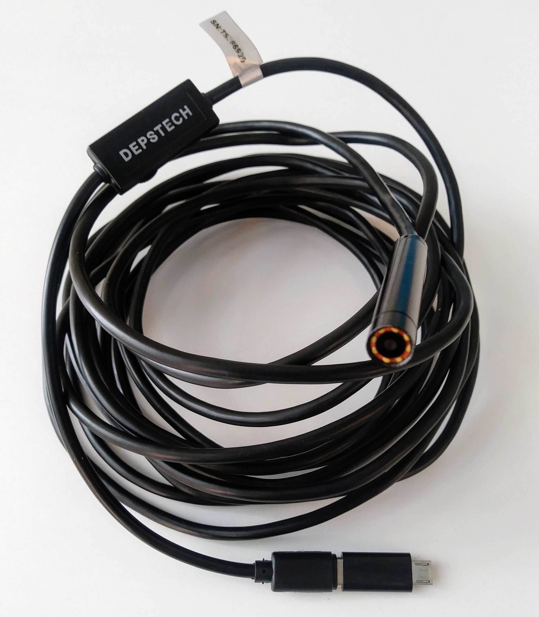
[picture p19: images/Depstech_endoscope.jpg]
    </br>
   </p>

   Figure 1. This endoscope purchased from Depstech&reg; features a 5 meter-long semirigid cable, a 2.0 MP camera ringed with adjustable LED lights, and a type-c USB end with complementary USB and micro-USB extensions. See <strong> Special Components </strong> for more details.</br>
   </br>

   The role of the endoscope is to capture images of the sedimentation tank fluid at certain depths. The images will be lit by its light source, a ring of LED lights around the camera lens. To restrict its view to such depths, the endoscope is accompanied by a non-reflective material, such as matte rubber, fixed no more than an inch in front of its lens. The turbidity of the fluid is thus measured by intensity of light reflected back to the endoscope due to the presence of suspended solids. In fluid of low solids concentration, the endoscope should detect minimal reflection of light.

2. Expandable Ruler System <br/>

   Instead of using a marked reel, we are fabricating an expandable ruler system to measuring the length the endoscope has been lowered by. This system consists of multiple 20 cm long PVC panels marked at each centimeter. The panels are connected by hinges to expand and collapse in an accordion style, while the endoscope cable runs down the side of the panels through a series of loops, folding with the panels (see Figure 2). The width of the panels must be around 2 inches or less in order to fit through the sedimentation tank opening.

   Thus, the user may lower the system panel by panel until the endoscope has reached the sludge blanket. The height of the sludge blanket would equal the depth of the endoscope (measured by the panel markings) subtracted from the total height of the sedimentation tank. The advantages of this expandable system are its collapsibility, making it ideal for transport, and the rigid backing it provides so that the endoscope wire, which is semi-rigid, remains perpendicular to the bottom of the tank, ensuring an accurate height reading.

   <p align="center">
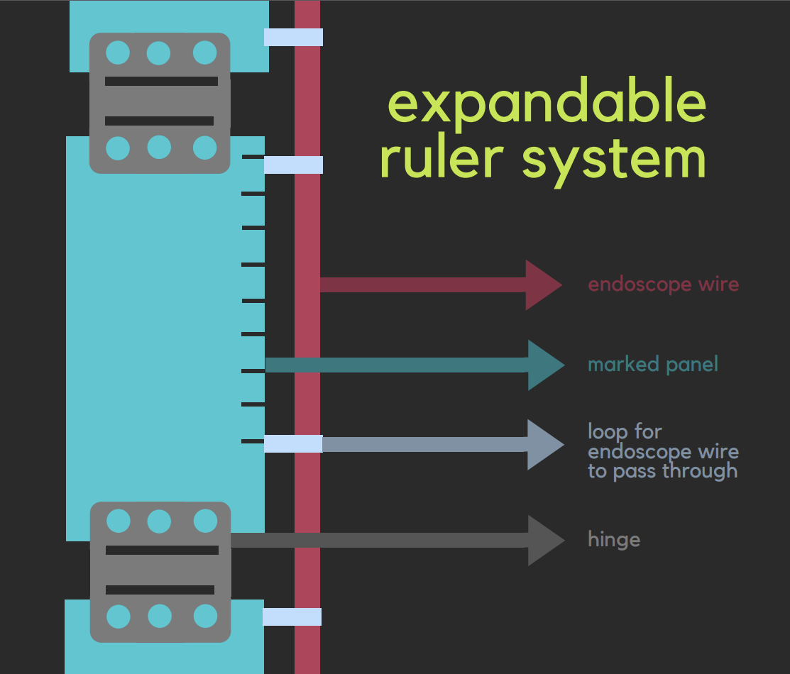
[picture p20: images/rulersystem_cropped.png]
   
   </p>
   Figure 2. The expandable ruler system consists of multiple marked panels connected by hinges end-to-end. (Only a portion of the entire system is shown.) The endoscope cable runs down the side of the panels through a series of loops. </p>

   <p align="center">
   
   </p>
   Figure 3. Above is a prototype of the expandable ruler system, constructed with two PVC panels, plastic loops, and plastic hinges. The prototype is able to collapse (left) for compact storage and also expand (right) to provide a straight, rigid backing for the endoscope cord when hung vertically. </br>
   </br>

3. Mobile Device and Application <br/>
   The mobile device is a smartphone or tablet computer provided by the user. It connects to the endoscope by a USB-C, USB, or Micro USB connection and runs the mobile application that we are in the process of programming.

   The application will collect live images taken by the endoscope, process each one for average light intensity, and calculate the turbidity of the fluid in each image. This calculation will use an empirically obtained correlation between turbidity and the intensity of reflected light (yet to be developed), as well as offset for any light detected during calibration in clear fluid. See **MAPE Code** for sample processing code.

   The mobile application will also provide a user-friendly interface by directing the user to calibrate the sensor, prompting the user to lower the endoscope to greater depths, and displaying the camera stream and calculated turbidity at each depth. In addition, it will record and graphically plot each calculation to track the change in turbidity as the endoscope nears the sludge blanket. The height of the sludge blanket can be determined once the turbidity rapidly increases or reaches a threshold value.

**Microcontroller-Interfaced Analog (MIA) Sensor** <br/>
The microcontroller-interfaced analog sensor also encompasses three main physical components: 1) the analog photodiode, 2) an expandable ruler system, and 3) a microcontroller programmed to convert and displays data from the endoscope and interact with the user.

1. Analog Photodiode<br/>
   We had previously been using an analog turbidity sensor, however because of its unreliability and sensitivity to noise, we were forced to use a photodiode instead. The specific photosensor that we used was the TEMT6000 Ambient Light Sensor. See <strong> Special Components </strong> for details and image source. </p>

2. Expandable Ruler System<br/>
   This expandable ruler system is the same as that of the MAPES sensor system. We will fabricate it in the same way but the endoscope will be replaced by the photosensor.

3. Microcontroller <br/>
   The microcontroller we are using is the Arduino&reg; UNO. The Arduino will read the output from the analog photosensor and convert that value into a turbidity reading. The developers of the sensor have published a tentative relation; however, further testing must be done to prove the validity of the relation. If the readings do not correlate to accurate turbidity, we may have to empirically develop a relation of our own. The microcontroller will also feature a digital display for the turbidity reading and a pushbutton for calibrating the sensor in clear fluid.

   See **Special Components** for details on the Arduino microcontroller and **MIA Code** for sample code.

## Fabrication

**Fabrication for the MAPE Turbidity Sensor** <br/>
   The only modification necessary for the endoscope is the addition of an extension for the non-reflective material. The extension includes two rectangular plates, one attached to the endoscope body, and the other extending off the endoscope and holding the non-reflective material in front of the camera lens. The two plates are screwed to and connected by two standoffs. The former standoff contains a hole the size of the endoscope so that the endoscope may slide through and be fixed to the plate with glue or another sealant.  

   The optimal distance from the camera lens to the non-reflective material is determined as the lowest distance for which the material reflects an acceptably low amount of light (with "acceptable" defined as reflecting light almost uniformly rather than in a bright spot or halo). Note that minimizing the distance minimizes the size and diameter of the sensor. For our endoscope and with matte rubber as the non-reflective material, we estimate a distance of 1.5 cm. Using the distance ($D$) and the field of view ($\theta$) angle of the endoscope (60º for ours), the minimum width ($W$) of the non-reflective material and the plates is:

   $W = D \cdot 2tan(\frac{\theta}{2}) = 1.5 \cdot \frac{2}{\sqrt{3}}  ≈ 1.732 cm$

   All parts can be made of plastic or metal, except the non-reflective material, for which we suggest matte rubber. Below is a rendering of the extension. <br/>

   <p align="center">
   <!-- <img src="/drawings/MAPE_extension.png" height=300>-->
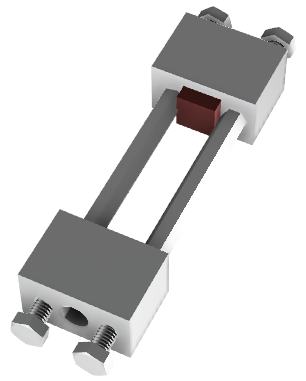
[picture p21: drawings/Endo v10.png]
    </br>
   </p>
   Figure 5. The extension includes two rectangular plates, one attached to the endoscope body, and the other extending off the endoscope and holding the non-reflective material in front of the camera lens. The two plates are screwed to and connected by two standoffs. Find the Fusion 360&trade; file for the extension <a href="https://github.com/AguaClara/sensor_dev/blob/master/drawings/Endo%20v9.iges"> here</a>. </br>
   </br>

 **Variables**
 </br>
 </br><p align="center">Table 1: List of Variables Used in MAPE Sensor Fusion Drawing
| Variables |  Description | Value |
|:--- |:---:| --- |
| rec_width | width of plate  |  2 cm |
| rec_length | length of plate | 3.5 cm |
| standoff_diam |  diameter of standoffs | .7 cm |
| rec_thickness | thickness of metal plates |  3 cm |
| endoscope_diam | diameter of endoscope |  5/16 in |
| screw_diam | diameter of threads |  5/32 in |
| disttoedge | distance from screw to edge of plate | .05 cm |
| screw_leng | length of threads | .6 cm |
| screw_poly | diameter of hex screw head rubber |  .7 cm |
| chamfer | length of chamfer at bottom of screw | .6 cm |
| fillet | length of fillet beneath head of screw | .6 cm |

<br/>

<br/>

**Fabrication for the MIA Turbidity Sensor** <br/>
   The main fabrication required for the MIA turbidity sensor is waterproofing the circuitry. The wires are hidden in flexible tubing which is thick enough to make sure that no water will enter and damage the sensor. We are still experimenting with ways to waterproof the photosensor however, because we do not want to damage the circuitry. The LED should be easily waterproofed with some silicon, which we plan to do the following semester. <br/>

   We plan to fabricate a case for the microcontroller for protection and easy handling and for holding the digital display. It will also include a rubber button connected to a pushbutton on the microcontroller to allow the user to calibrate the sensor. The design for the case not yet been finalized.

   **Fabrication for the Expandable Ruler System** </br>
   As mentioned before, the Expandable Ruler System is made up of multiple 20 cm long PVC panels marked at each centimeter. Each of the panels are connected by double hinges to expand and collapse. The endoscope cable runs down the side of the panels through a series of loops which we attach to the side of the PVC panel (see Figure 2). Although we used single hinges for the prototype (see Special Components), we plan to use a double hinge in future iterations. Please refer to Figure 3 for the prototype.

## Special Components

#### MAPES Turbidity Sensor
**Endoscope/ Borescope:** </br>
   The endoscope we used was purchased through Amazon and was developed by Depstech&reg;. [Click here to view.](https://www.amazon.com/Depstech-Semi-rigid-Inspection-Waterproof-Adjustable/dp/B0749BQG1B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) Product specifications can be found on the given website as well. Although we chose this particular endoscope, there are other similarly viable endoscopes and borescopes available.

#### MIA Turbidity Sensor
**Analog Turbidity sensor** </br>
   The specific photosensor used was the TEMT6000 Ambient Light Sensor made by SparkFun. TEMT6000 is a silicon NPN epitaxial planar photo-transistor in a miniature transparent mold for surface mounting onto a printed circuit board. The device is sensitive to wavelengths from 390 nm to 700 nm. It is available [here.](https://www.sparkfun.com/products/8688)
**Arduino&reg; UNO**  </br>
   The Arduino UNO can be purchased through the [Arduino website](https://www.arduino.cc/). The Arduino IDE is also available [here](https://www.arduino.cc/en/Main/Software) for free.

#### Expandable Ruler System
**Hinges** </br>
   The plastic hinges used in the prototype can be found [here](https://www.mcmaster.com/#1635a25/=1c2z1rq).

## Experimental Methods

### Current Experimental Methods
Because we are still in the fabrication and programming process, we are not able to test at this time. However, we are intermittently checking to see if the analog photosensor for the MIA turbidity work correctly. We do this by using print statements and checking to see that there is ample fluctuation and a significant difference between high and low turbidities.

```arduino

int ledPin = 13;          //declaration for LED
int button = 11;          //digital input of the pushbutton
int offset = 0;           //set the offset as zero for now
int turb_input = A1;      //input in A0 from sensor
int flag = 0;             //if flag is 1, start loop

void setup() {
  // put your setup code here, to run once:
  Serial.begin(9600);
}

void loop() {
  // put your main code here, to run repeatedly:
  int test=analogRead(turb_input);
  Serial.println('\n');
  Serial.println("reading from the input");
  Serial.println(test);

}

```

### Future Experimental Methods

To test our sensors, we will submerge each into fluids of known solids concentration and turbidity. We will then analyze collected outputs for a relation between actual concentration and measured turbidity. It may also be necessary to test the effects of different types, particularly different colors, of sediment on the turbidity readings. However, we are not yet at the testing phase and have no experimentation details yet to report.

## MAPE Turbidity Sensor Code

This is a sample of code written in Java for displaying a video stream from the endoscope and processing its images for average light intensity. For the full set of classes required for this program, browse our Github repository at AguaClara/sensor_dev/code/Endoscope Pilot Code (or click [here](https://github.com/AguaClara/sensor_dev/tree/master/code/Endoscope%20Pilot%20Code).
```java
/* Framework for video frame capture, conversion, and display adapted from
* http://computervisionandjava.blogspot.com/2013/10/java-opencv-webcam.html
*/

import java.awt.Graphics;
import java.util.Date;

import javax.swing.JFrame;
import javax.swing.JPanel;
import javax.swing.border.EmptyBorder;

import org.opencv.core.Mat;
import org.opencv.imgproc.Imgproc;

public class EndoscopeFrame extends JFrame {
    private JPanel contentPane;
    VideoCap videoCap;

	public static void main(String[] args) {
        try {
            EndoscopeFrame frame = new EndoscopeFrame();
            frame.setVisible(true);
        } catch (Exception e) {
            e.printStackTrace();
        }
	}

	public EndoscopeFrame() {
        setDefaultCloseOperation(JFrame.EXIT_ON_CLOSE);
        setBounds(0, 0, 1280, 960);
        contentPane = new JPanel();
        contentPane.setBorder(new EmptyBorder(5, 5, 5, 5));
        setContentPane(contentPane);
        contentPane.setLayout(null);

        videoCap = new VideoCap(1);
        //0 or nothing for default camera (for a computer, the webcam)
        //1 or higher for additional cameras (e.g. the USB endoscope camera)

        new MyThread().start();
    }

    public void paint(Graphics g){
        g = contentPane.getGraphics();
        g.drawImage(videoCap.getOneImgFrame(), 0, 0, this);

        if (counter % 10 == 0)
          System.out.println("Average Light: " + averageLight(videoCap.mat2Img.mat, 10));
    }

    public static int averageLight(Mat mat, int spacing) {
    		Imgproc.cvtColor(mat, mat, Imgproc.COLOR_BGR2GRAY);
    		int[][] pixelShades = new int[mat.rows()/spacing+1][mat.cols()/spacing+1];
    		int sum = 0;

    		for (int r = 0; r < mat.rows(); r += spacing) {
    			for (int c = 0; c < mat.cols(); c += spacing) {
    				pixelShades[r/spacing][c/spacing] = (int) mat.get(r, c)[0];

    				sum += pixelShades[r/spacing][c/spacing];
    			}
    		}

    		return sum/pixelShades.length/pixelShades[0].length;
    }

    class MyThread extends Thread{
        @Override
        public void run() {
            while (true) {
                repaint();
                try { Thread.sleep(30);
                } catch (InterruptedException e) { }
            }
        }
    }
}
```

Sample Output:
<p align="center">
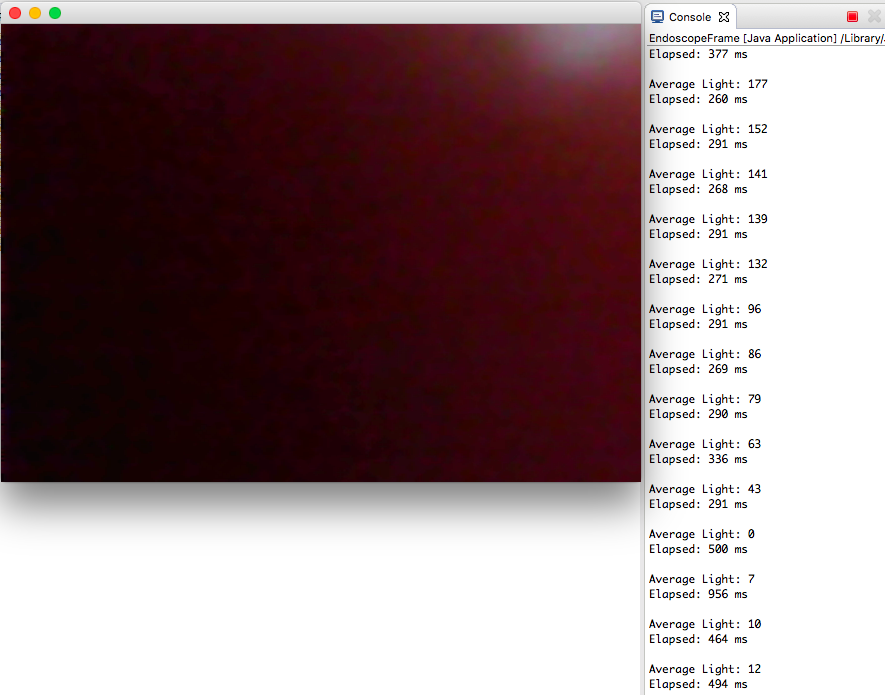
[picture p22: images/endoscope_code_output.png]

</p>
Figure 7. Above is a sample output of the program for the MAPE turbidity sensor produced by exposing the camera to light and then quickly covering it. Hence, the "Average Light" values that fall from near 200 to 0. Additional code was written for printing elapsed time between calculations. </p>

Below is a Java file for a mobile Android application that streams camera feedback from the phone's own camera(s) with constant exposure. For future work, the application must access the endoscope, an external camera to the smartphone, and integrate the image processing code from above. For the full project, written in Android Studio&reg; using Android libraries, browse our Github repository at AguaClara/sensor_dev/code/AguaClara Turbidity (or click [here](https://github.com/AguaClara/sensor_dev/tree/master/code/AguaClara%20Turbidity)).

```java
package me.aguaclaraturbidity;

import android.content.pm.PackageManager;
import android.support.v4.app.ActivityCompat;
import android.support.v4.content.ContextCompat;
import android.support.v7.app.AppCompatActivity;
import android.os.Bundle;

import android.util.Log;
import android.view.SurfaceHolder;
import android.view.SurfaceView;
import android.hardware.Camera;
import android.widget.SeekBar;
import android.widget.TextView;

import java.io.IOException;

public class MainActivity extends AppCompatActivity implements SurfaceHolder.Callback, Camera.PreviewCallback {
    private Camera camera;
    private Camera.Parameters camParams;

    @Override
    public void onCreate(Bundle savedInstanceState) {
        super.onCreate(savedInstanceState);

        setContentView(R.layout.activity_main);
        SurfaceView cameraPreview = (SurfaceView) findViewById(R.id.camera_preview);

        ActivityCompat.requestPermissions(this, new String[]{android.Manifest.permission.CAMERA}, 50);

        if (ContextCompat.checkSelfPermission(getApplicationContext(), android.Manifest.permission.CAMERA)
        == PackageManager.PERMISSION_GRANTED) {
            openCamera(0);
            try {
                cameraPreview.getHolder().addCallback(this);
                camera.setPreviewDisplay(cameraPreview.getHolder());
                camera.setPreviewCallback(this);
                camera.startPreview();
            } catch (IOException e) {
                e.printStackTrace();
            }
        }
    }

    public void openCamera(int id){
        releaseCameraAndPreview();
        camera = Camera.open(id);
        camera.setDisplayOrientation(90);
        camParams = camera.getParameters();
    }

    private void releaseCameraAndPreview() {
        if (camera != null) {
            camera.stopPreview();
            camera.release();
            camera = null;
        }
    }

    @Override
    public void surfaceCreated(SurfaceHolder surfaceHolder) {
        try {
            camera.setPreviewDisplay(surfaceHolder);
            camera.startPreview();
        } catch (IOException e) {
            Log.d("View", "Error setting camera preview: " + e.getMessage());
        }
    }

    @Override
    public void surfaceChanged(SurfaceHolder surfaceHolder, int i, int i1, int i2) {
    }

    @Override
    public void surfaceDestroyed(SurfaceHolder surfaceHolder) {
        if (camera != null) {
            camera.stopPreview();
        }
    }

    @Override
    public void onPreviewFrame(byte[] bytes, Camera camera) {
        camParams.setExposureCompensation(0);
        camera.setParameters(camParams);
    }
}
```
<p align="center">
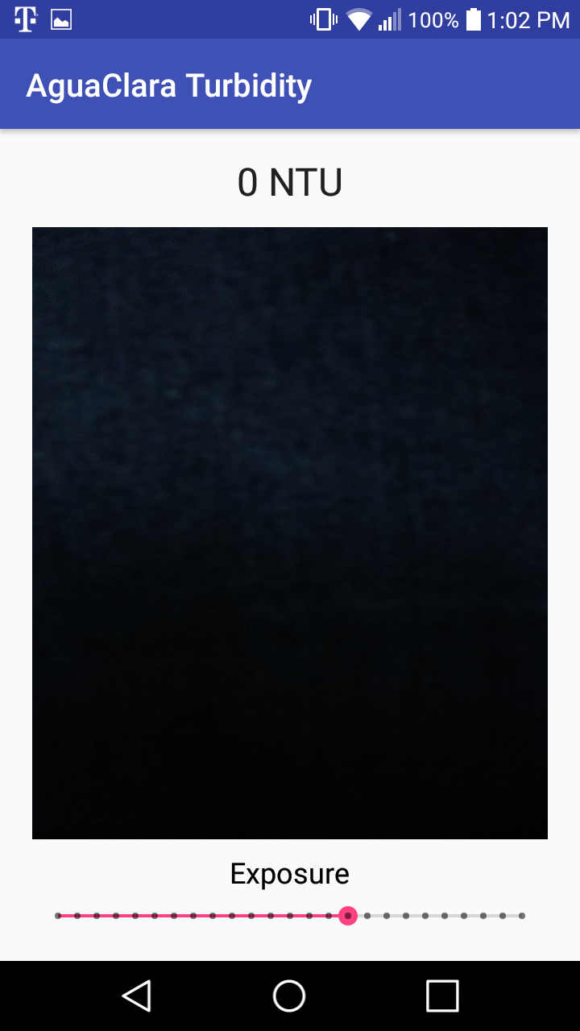
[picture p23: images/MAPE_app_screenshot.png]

<p/>
Figure 8. This is a screenshot of the mobile Android application for the MAPE turbidity sensor. The camera feedback is from the phone's rear camera, as the application is not yet able to access an external camera such as the endoscope. The user may adjust the exposure level, though between adjustments the exposure is held constant.

## MIA Code

This C code is to program the Arduino Uno for the MIA sensor. It uses the input from the sensor and the relation provided by the vendors and developers to determine a turbidity. (Programmed with the Arduino IDE)

```arduino
//global variables

int ledPin = 13;          //declaration for LED
int button = 11;          //digital input of the pushbutton
int offset = 0;           //set the offset as zero for now
int turb_input = A0;      //input in A0 from sensor
int flag = 0;             //if flag is 1, start loop

float turbidity = 0.0;    //turbidity
int threshold = 700;     //threshold turbidity for sludge blanket

void setup() {

  Serial.begin(9600);           //Baud rate: 9600
  pinMode(ledPin, OUTPUT);      //This is to set up the LED
  pinMode(turb_input, INPUT);   //This is to set up the input from sensor
  pinMode(button, INPUT);       //This is to set up the input from pushbutton

  //CALIBRATION
  Serial.println('\n');
  Serial.println("Please calibrate the sensor by pressing the button");

  //PUSHBUTTON
  if (digitalRead(button)==LOW){
    flag = 0;
  }

  else if(digitalRead(button) == HIGH){
    offset = analogRead(turb_input);
    Serial.println('\n');
    Serial.print("this is the offset value:");
    Serial.println(offset);
    delay(500);
    flag = 1;
  }
  }

void loop() {

 // if (flag == 1){
    int sensorValue = analogRead(turb_input);// read the input on A0:

    // Convert the analog reading (which goes from 0 - 1023) to a voltage (0 - 5V):
    float voltage = sensorValue * (5.0 / 1024.0);
    Serial.println("____________________________________");
    Serial.print("this is the reading from the analog:");
    Serial.println(sensorValue); // print out the value you read:

    Serial.print("this is the voltage reading:");
    Serial.println(voltage); // print out the value you read:

    // Convert voltage to turbidity
    // relation from page is -1120.4x^2 +5742.3x-4352.9
    // only supports voltages of 2.5-4.2 for the relation

    if (voltage > 2.5 && voltage < 4.2){
      turbidity = (voltage*voltage*(-1120.4))+(voltage*5742.3)-4352.9-(offset);
    }
    else if (voltage < 2.5){
      turbidity = 3000;
    }
    else if (voltage > 4.2){
      turbidity = 0;
    }
      Serial.print("this is the turbidity reading:");
      Serial.println(turbidity); // print out the value you read:
      delay(500);

    //threshold value to compare to light up LED
    if (turbidity > threshold){
      digitalWrite(ledPin, HIGH);
      Serial.println("YOU ARE NOW IN THE SLUDGE BLANKET");
    }
    else {
      digitalWrite(ledPin, LOW);
    }
  }
```

<!-- ```python
# To convert the document from markdown to pdf
pandoc manual_1.md -o Sensor_Development_Research_Report.pdf
``` -->

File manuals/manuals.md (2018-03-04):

Manuals

[Spring 2018 Manual 1](manual_1.md)

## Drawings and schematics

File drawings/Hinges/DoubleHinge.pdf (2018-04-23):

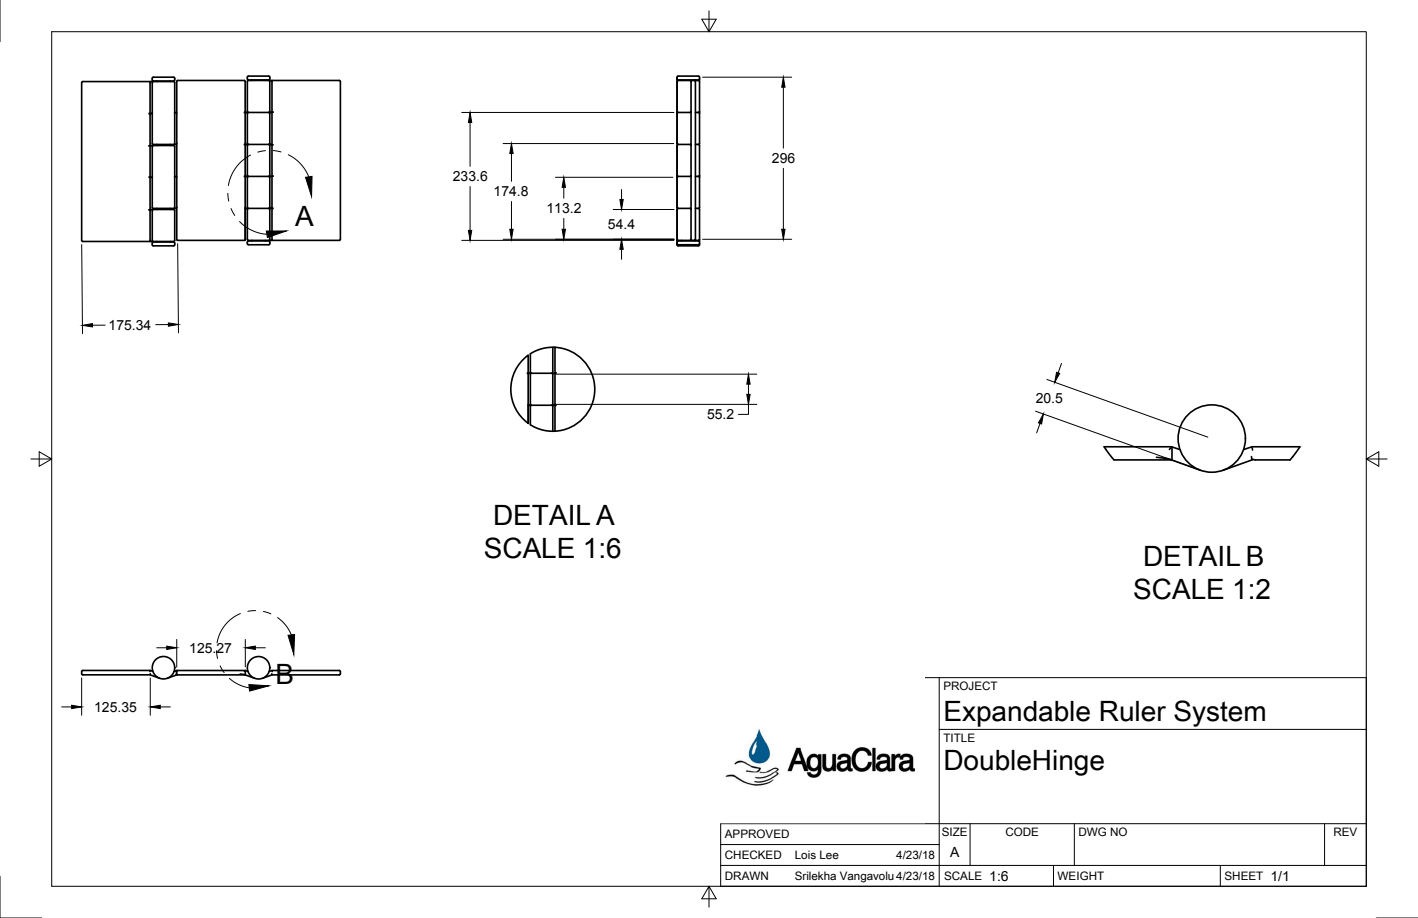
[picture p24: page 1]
SIZE; CODE; DWG NO; REV; Srilekha Vangavolu 4/23/18; Lois Lee; DETAIL A SCALE 1:6; DETAIL B SCALE 1:2

PROJECT
Expandable Ruler System
DoubleHinge

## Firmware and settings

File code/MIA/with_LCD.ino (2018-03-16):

/*
 * MIA code with Liquid Crystal Display
 * This code's function is to take the input voltage from the turbidity sensor
 * and translate it into a numerical value for turbidity
 * 
 * The circuit:
 * LCD RS pin to        digital pin 12
 * LCD Enable pin to    digital pin 11
 * LCD D4 pin to        digital pin 5
 * LCD D5 pin to        digital pin 4
 * LCD D6 pin to        digital pin 3
 * LCD D7 pin to        digital pin 2
 * LCD R/W pin to       ground
 * LCD VSS pin to       ground
 * LCD VCC pin to       5V
 * 10K resistor:
 * ends to +5V and ground
 * wiper to LCD VO pin (pin 3)
 * 
 */

//global variables

int ledPin = 13;          //declaration for LED
int button = 11;          //digital input of the pushbutton
int offset = 0;           //set the offset as zero for now
int turb_input = A0;      //input in A0 from sensor
int flag = 0;             //if flag is 1, start loop

float turbidity = 0.0;    //turbidity
int threshold = 2500;     //threshold turbidity for sludge blanket

//initialize LCD library
const int rs = 12, en = 11, d4 = 5, d5 = 4, d6 = 3, d7 = 2;
LiquidCrystal lcd(rs, en, d4, d5, d6, d7);

//setup
void setup() {
  
  Serial.begin(9600);           //Baud rate: 9600 
  pinMode(ledPin, OUTPUT);      //This is to set up the LED
  pinMode(turb_input, INPUT);   //This is to set up the turbidity input from sensor
  pinMode(button, INPUT);       //This is to set up the input from pushbutton

  //CALIBRATION   
  //set up so that the difference between the clear water turbidity
  //and the usual 0 turbidity value and set this as the constant offset 
  //as Hannah pointed out, this will also take care of the temp difference
  //(this will be used in the conversion)
  Serial.println('\n');
  Serial.println("Please calibrate the sensor by pressing the button");  //clear water calibration
  
  //PUSHBUTTON
  //set it up with a push button
  if (digitalRead(button)==LOW){ 
    //don't remember if pushbutton high or low when pressed
    flag = 0;
  }
  
  else if(digitalRead(button) == HIGH){     
    //whole thing could possibly be moved into loop()
    offset = analogRead(turb_input);
    Serial.println('\n');
    Serial.print("this is the offset value:");   //but then get rid of flag=0
    Serial.println(offset);
    delay(500);
    flag = 1;
  }

  // set up the LCD's number of columns and rows:
  lcd.begin(16, 2);
  // Print begin msg
  lcd.print("begin readings");
  }


void loop() {

 // if (flag == 1){
    int sensorValue = analogRead(turb_input);// read the input on A0:

    // Convert the analog reading (which goes from 0 - 1023) to a voltage (0 - 5V):
    float voltage = sensorValue * (5.0 / 1024.0); 
    Serial.println("____________________________________");
    Serial.print("this is the reading from the analog:");
    Serial.println(sensorValue); // print out the value you read:
  
    
    Serial.print("this is the voltage reading:");
    Serial.println(voltage); // print out the value you read:
  

    // Convert voltage to turbidity
    // relation from page is -1120.4x^2 +5742.3x-4352.9
    // only supports voltages of 2.5-4.2 for the relation
    
    if (voltage > 2.5 && voltage < 4.2){
      //this relation needs to be fixed as well 
      //this fixes the problem with the negative numbers
      turbidity = (voltage*voltage*(-1120.4))+(voltage*5742.3)-4352.9-(offset);
    }
    else if (voltage < 2.5){
      turbidity = 3000;
    }
    else if (voltage > 4.2){
      turbidity = 0;
    }

      Serial.print("this is the turbidity reading:");
      Serial.println(turbidity); // print out the value you read:
      delay(500);

        lcd.setCursor(0, 1);
        // print the reading on LCD
        lcd.print(turbidity);
      
    //threshold value to compare to light up LED
    if (turbidity > threshold){
      digitalWrite(ledPin, HIGH);
      Serial.println("YOU ARE NOW IN THE SLUDGE BLANKET");
    }
    else {
      digitalWrite(ledPin, LOW);
    }
    
    
    // }  
    //later add breadboard stuff with display
  }

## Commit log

2018-03-08 Wrote "Product Details" for MAPE turbidity sensor
2018-03-10 Mostly finished, still needs CAD drawings, maybe some Java code, and fine tuning
2018-03-15 edited CAD picture link
2018-03-20 Added code for getting average light intensity of pixels and methods for statically converting Mat to BufferedImages (though currently unused)
2018-03-26 MAPE v5 Fusion File
    [MAPE v5.f3d]
2018-04-23 Double Hinge
2018-04-23 added sensor images
2018-04-23 One of the shaft collars has been taken out
    Also the decal has been rotated 90 degrees and scaled 1.5 in the xy plane.
2018-04-24 MAPE v8
    [MAPE v8.f3d]
2018-05-16 Added android app code for MAPE turbidity sensor and renamed endoscope code folder. Currently the app can display a camera preview from the phone's front and rear camera and hold the exposure constan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
2018-05-18 addressed and deleted most comments, changed analog turbidity sensor to photodiode, added info about MAPE extension and Android app
2018-05-18 Added new MAPE extension picturue to manual and reorganized drawings
    [DoubleHinge v7.f3d, MAPE v5.f3d, MAPE v8.f3d]
